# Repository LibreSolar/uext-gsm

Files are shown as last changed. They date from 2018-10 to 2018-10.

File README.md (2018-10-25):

# GSM board based on SIM800L for UEXT connector

## Features

- Separate power supply from 12V or 5V (GSM board needs 4.2V and 2A)
- Reverse polarity protection for separate power supply
- UEXT connector to communicate with host MCU

### Top side 

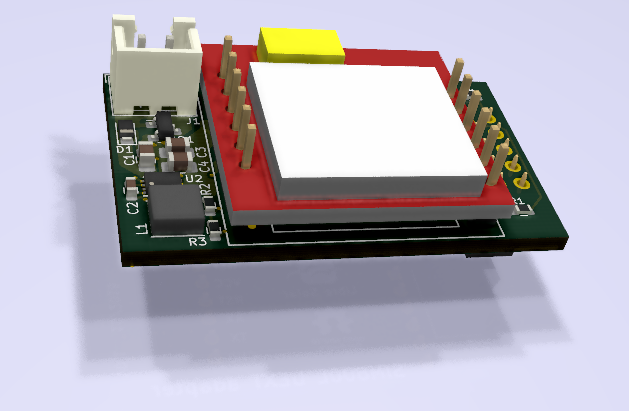
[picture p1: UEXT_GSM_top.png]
Top side of the PCB


### Bottom side

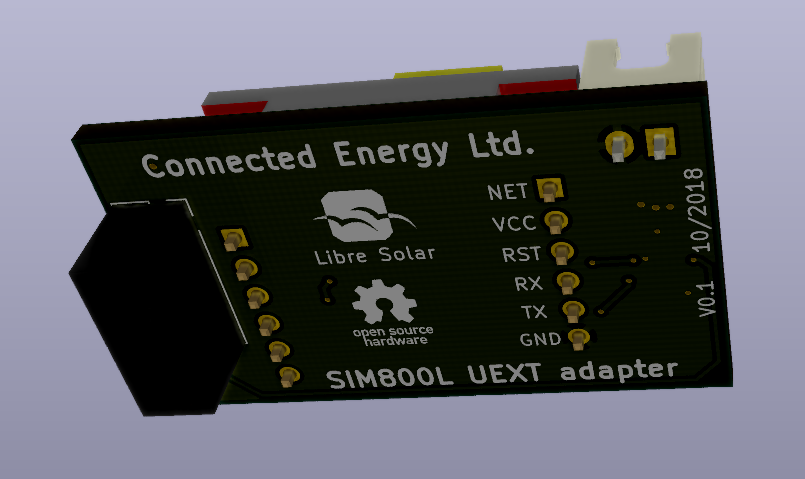
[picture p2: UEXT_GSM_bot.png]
Bottom side of the PCB


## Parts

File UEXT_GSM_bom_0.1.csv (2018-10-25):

Component | Description | Part | References | Value | Footprint | Quantity Per PCB | Datasheet | Remarks | PartNumber | Manufacturer | DNP
1 | Unpolarized capacitor | C | C1 | 10uF | C_0805_2012 | 1 |  | Alternative: TDK C2012X5R1E106K085AC | GRM21BC71E106KE11L | Murata
2 | Unpolarized capacitor | C | C2 | 2.2n | C_0603_1608 | 1 |  | minimum 10V, X5R | 885012206085 | Würth
3 | Unpolarized capacitor | C | C3 C4 | 22uF | C_0805_2012 | 2 |  | minimum 10V, X5R | LMK212BBJ226MG-T | Tayo Yuden
4 | Diode Schottky | D_Schottky | D1 | RSX051VAM30TR | D_TUMD2 | 1 |  |  | RSX051VAM30TR | ROHM
5 | Generic connector, single row, 01x02, script generated (kicad-library-utils/schlib/autogen/connector/) | Conn_01x02_Male | J1 | Conn_01x02_Male | JST_XH_B02B-XH-A_1x02_P2.50mm_Vertical | 1 | ~ |  |  |  | X
6 |  | UEXT | J2 | UEXT | PinSocket_2x05_P2.54mm_Vertical | 1 | http://wppro.com/content/de/produkte/buchsenleisten/raster-2_54mm/product/157b.pdf |  | 157B-05-2-00 | W+P
7 | Inductor | L | L1 | 2.2uH | L_Coilcraft_XxL4020 | 1 |  |  | XFL4020-222 | Coilcraft
8 |  | LibreSolar_Logo | LOGO1 | LibreSolar_Logo | LIBRESOLAR_LOGO | 1 |  |  |  |  | X
9 | Transistor N-MOSFETwith substrate diode (general) | Q_NMOS_GSD | Q1 | DMN3023L-7 | SOT-23 | 1 |  |  | DMN3023L-7 | Diodes Incorporated
10 | Resistor | R | R4 | 0R | R_0603_1608 | 1 |  |  |  |  | X
11 | Resistor | R | R1 R3 | 100k | R_0603_1608 | 2 |  |  | RC0603FR-07100KL | Yageo
12 | Resistor | R | R2 | 499k | R_0603_1608 | 1 |  |  | RC0603FR-07499KL | Yageo
13 |  | SIM800L | U1 | SIM800L | Sim800L | 1
14 | 3A Step-Down Converter with DCS-Control, Adjustable Output Voltage, 3-17V Input Voltage, QFN-16 | TPS62147 | U2 | TPS62147 | VQFN_RGX0011A | 1 | http://www.ti.com/lit/ds/symlink/tps62130.pdf |  | TPS62147RGXR | Texas Instruments
Component Groups: | 14
Component Count: | 16
Fitted Components: | 16
Number of PCBs: | 1
Total components: | 16
Schematic Version: | 0.1
Schematic Date: | 2018-10-24
BoM Date: | Do 25 Okt 2018 14:22:35 CEST
Schematic Source: | /home/martin/LibreSolar/2_Development/04_Hardware/UEXT_GSM/UEXT_GSM.sch
KiCad Version: | Eeschema 5.0.0

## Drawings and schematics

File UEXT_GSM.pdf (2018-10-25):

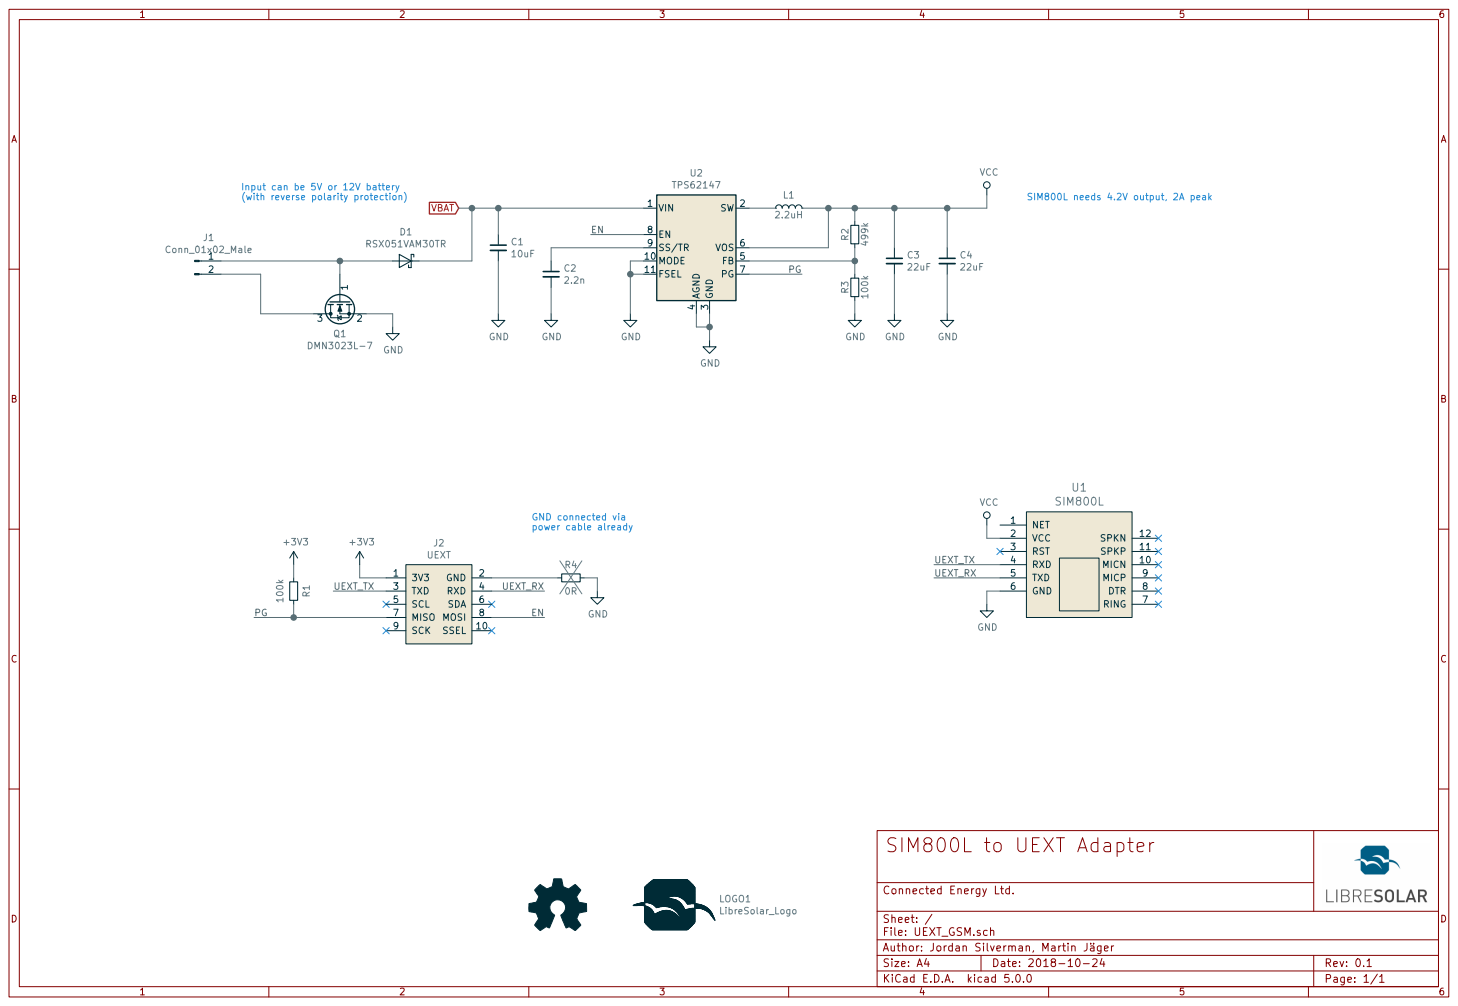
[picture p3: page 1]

4 FB 5 VOS 6 PG 7 EN 8 SS/TR 9 U2 TPS62147

Input can be 5V or 12V battery

File: UEXT_GSM.sch Sheet: / Connected Energy Ltd.

Author: Jordan Silverman, Martin Jäger

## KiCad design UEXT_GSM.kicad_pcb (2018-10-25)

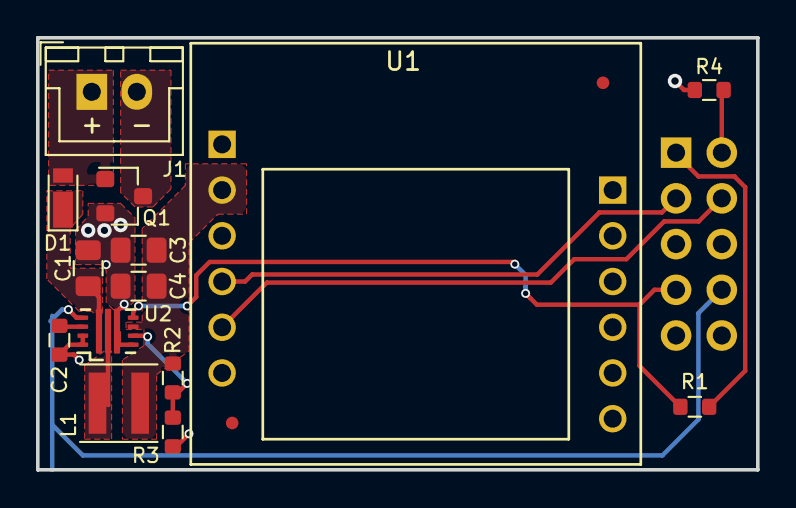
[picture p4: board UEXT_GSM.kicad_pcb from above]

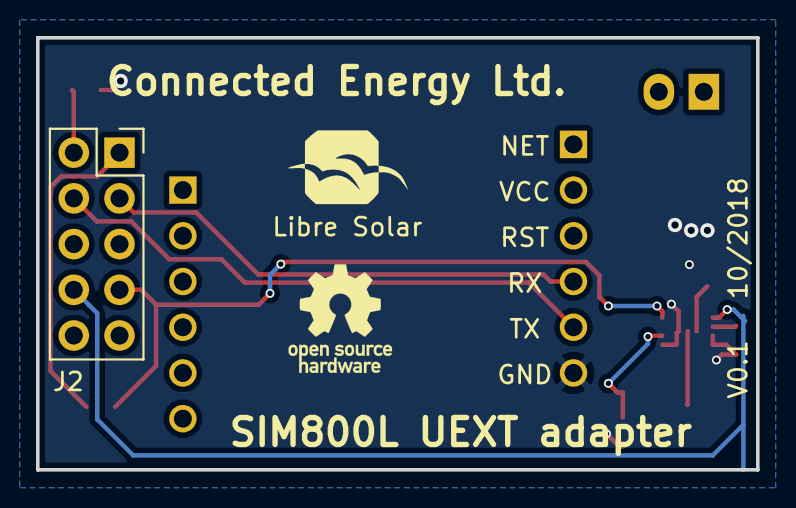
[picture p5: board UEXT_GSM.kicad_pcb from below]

Board: 2 copper layers, 40.0 x 24.0 mm, 16 parts (2 on the bottom side), 14 nets.

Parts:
C1: 10uF; C_0805_2012
C2: 2.2n; C_0603_1608
C3, C4: 22uF; C_0805_2012
D1: RSX051VAM30TR; D_TUMD2
J1: Conn_01x02_Male; JST_XH_B02B-XH-A_1x02_P2.50mm_Vertical
J2: UEXT; PinSocket_2x05_P2.54mm_Vertical
L1: 2.2uH; L_Coilcraft_XxL4020
LOGO1: LibreSolar_Logo; LIBRESOLAR_LOGO
Q1: DMN3023L-7; SOT-23
R1, R3: 100k; R_0603_1608
R2: 499k; R_0603_1608
R4: 0R; R_0603_1608
U1: SIM800L; Sim800L
U2: TPS62147; VQFN_RGX0011A

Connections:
+3V3: J2.1, R1.2
/EN: J2.8, U2.8
/PG: J2.7, R1.1, U2.7
/UEXT_RX: J2.4, U1.5
/UEXT_TX: J2.3, U1.4
GND: C1.2, C2.2, C3.2, C4.2, Q1.2, R3.2, R4.2, U1.6, U2.3, U2.4, U2.10, U2.11
unnamed: C2.1, U2.9
unnamed: D1.2, J1.1, Q1.1
unnamed: J1.2, Q1.3
unnamed: J2.2, R4.1
unnamed: L1.1, U2.2
unnamed: R2.2, R3.1, U2.5
VBAT: C1.1, D1.1, U2.1
VCC: C3.1, C4.1, L1.2, R2.1, U1.2, U2.6
